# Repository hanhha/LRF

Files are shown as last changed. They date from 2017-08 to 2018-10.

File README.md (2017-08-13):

# LFR

A simple DIY laser range finder.

This is a very simple DIY laser range finder. For fast prototyping, I uses a Raspberry Pi 1 board with a web cam, a cheap laser diode (<5mW, I think) and some 3d printed bars to align the parts.

## Folder organization:

**src** - *all source code*

**eltr** - *all electric/electronic stuffs*

**model** - *all models of frame, mount, ... that would be 3d printed*

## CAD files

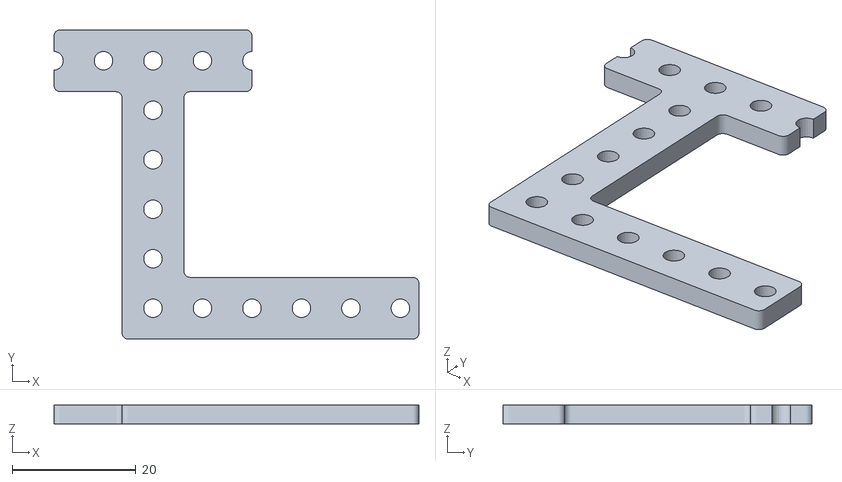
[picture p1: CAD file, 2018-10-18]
model/mount_L_shape.stl
59.0 x 50.0 x 3.00

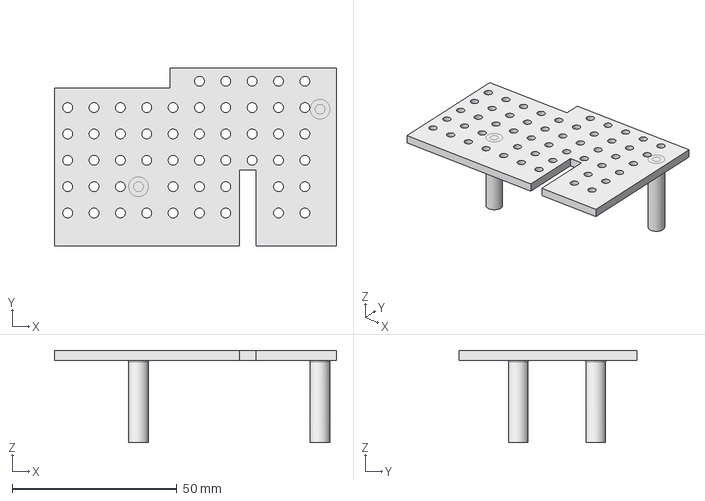
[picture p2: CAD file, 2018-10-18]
model/pi_top.FCStd
85.6 x 54.0 x 28.0 mm

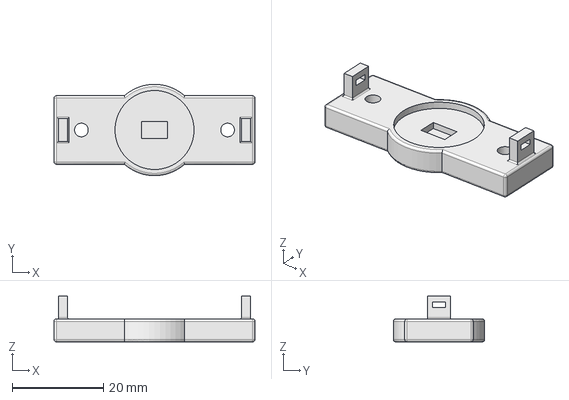
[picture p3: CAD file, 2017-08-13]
model/cam_mount.FCStd
44.0 x 20.0 x 10.0 mm

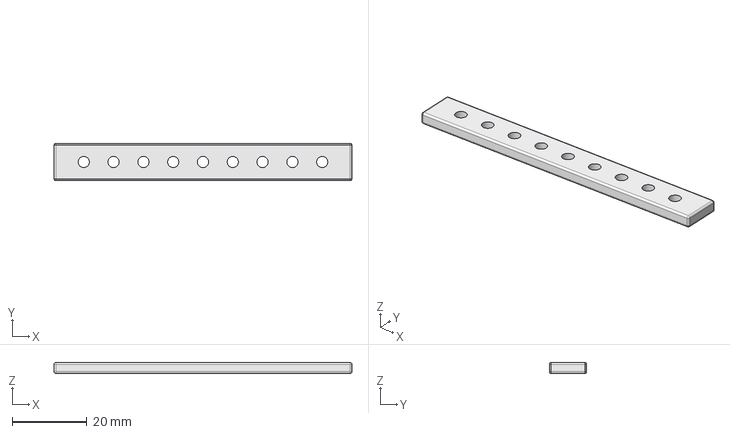
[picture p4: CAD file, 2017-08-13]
model/mount_bar.FCStd
80.0 x 10.0 x 3.00 mm

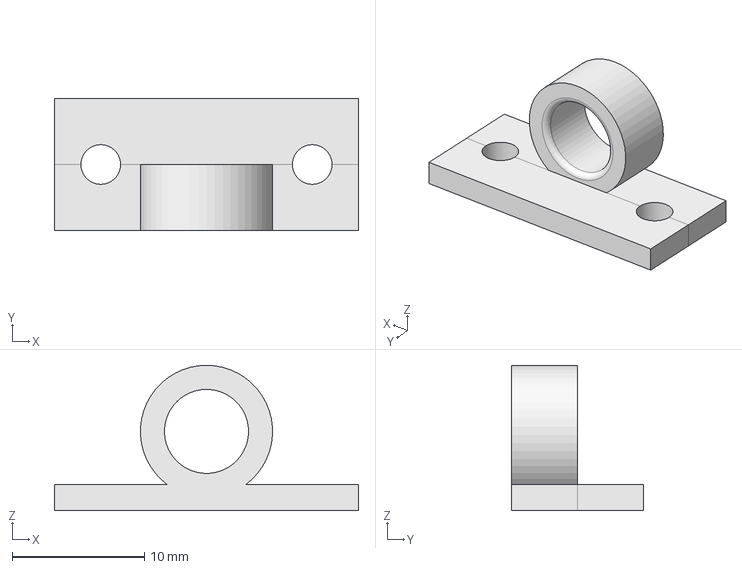
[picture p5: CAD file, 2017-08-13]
model/laser_diode_mount.FCStd
23.0 x 10.0 x 11.0 mm

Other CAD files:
model/mount_hLshape.FCStd
model/pi_top.stl

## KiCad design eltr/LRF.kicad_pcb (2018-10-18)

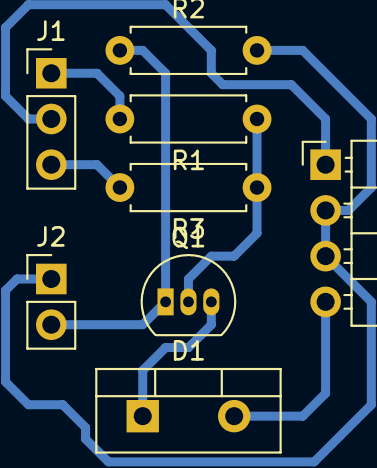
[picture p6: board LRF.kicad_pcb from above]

Board: 2 copper layers, 8 parts (0 on the bottom side), 8 nets.

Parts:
D1: Laser diode; TO-220-2_Vertical
J1: CONN_01X03_MALE; Pin_Header_Straight_1x03_Pitch2.54mm
J2: CONN_01X02_MALE; Pin_Header_Straight_1x02_Pitch2.54mm
P1: CONN_01X04; Pin_Header_Angled_1x04_Pitch2.54mm
Q1: PN2222A; TO-92_Inline_Narrow_Oval
R1: 100; R_Axial_DIN0207_L6.3mm_D2.5mm_P7.62mm_Horizontal
R2: 10K; R_Axial_DIN0207_L6.3mm_D2.5mm_P7.62mm_Horizontal
R3: 1K; R_Axial_DIN0207_L6.3mm_D2.5mm_P7.62mm_Horizontal

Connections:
+5V: D1.2, P1.4
GND: J2.1, P1.2, P1.3, R2.2
GPIO: J1.2, P1.1
unnamed: D1.1, Q1.3
unnamed: J1.1, R1.2
unnamed: J1.3, R3.2
unnamed: J2.2, Q1.1, R2.1
unnamed: Q1.2, R1.1, R3.1

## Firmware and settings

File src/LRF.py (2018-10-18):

#!/usr/bin/env python

import picamera as picam
from PIL import Image
from picamera.array import PiRGBArray
import numpy as np
import os
import RPi.GPIO as GPIO
import cv2

import curses

os.environ['SDL_VIDEODRIVER'] = 'fbcon'

imgDimensions = (800, 600)

camera = picam.PiCamera()
camera.resolution = imgDimensions 
camera.framerate = 40
camera.led = False
camera.iso = 30
camera.exposure_mode = 'snow'
rawCapture = PiRGBArray(camera, size=imgDimensions)

linear_params = {'A': 1, 'B': 0}

laserPin = 7

def laserSETUP ():
	GPIO.setup   (laserPin, GPIO.OUT)

def laserON ():
	GPIO.output (laserPin, GPIO.HIGH)

def laserOFF ():
	GPIO.output  (laserPin, GPIO.LOW)

def detectSpot (img):
	lab_img = cv2.cvtColor (img, cv2.COLOR_BGR2LAB)
	lw_range = np.array([240, 0,  0], dtype =np.uint8)
	up_range = np.array([255, 255, 255], dtype =np.uint8)
	mask = cv2.inRange (lab_img, lw_range, up_range)
	
	return mask

def getSpot (mask):
	spots = np.where (np.logical_and.reduce ((mask[0] == 255, mask[1] == 255)), 255, 0)
	return spots

def getSpotPos (spots):
	if spots[1].size == 0 or spots[0].size == 0:
		return None
	else:
		tmp = np.where (spots == 255)
		if tmp[1].size == 0 or tmp[0].size == 0:
			return None
		else:
			cx = np.sum (tmp[1]) / tmp[1].size 
			cy = np.sum (tmp[0]) / tmp[0].size 
			return (cx, cy)

def __main__ (stdscr):
	curses.init_pair (1, curses.COLOR_CYAN, curses.COLOR_BLACK)
	rate = 1
	stdscr.nodelay(1)

	GPIO.cleanup ()
	GPIO.setmode (GPIO.BOARD)
	laserSETUP   ()
	laserOFF     ()
	bg_mask      = None
	distance_txt = 'INF'
	mask         = []
	spots        = None
	laserSpot    = None
	phase        = 0

	for frame in camera.capture_continuous (rawCapture, format ="bgr", use_video_port=True):
		image = np.copy (frame.array) 

		if phase == 0:
			bg_mask = detectSpot(image)
			laserON ()
			mask = []
			phase = 1
		elif phase == 1:
			mask.append (detectSpot(image) - bg_mask)
			phase = 2
		elif phase == 2:
			mask.append (detectSpot(image) - bg_mask)
			phase = 3
		else:
			laserOFF ()
			phase = 0

			spots = getSpot (mask)
			laserSpot = getSpotPos (spots)
			if laserSpot is not None:
				p = laserSpot[0] - imgDimensions[0]/2
				if p != 0:
					distance = linear_params['A'] * float(p) + linear_params['B']
					distance_txt = str(distance) 
				else:
					distance_txt = 'INF'

		stdscr.move (1,1)
		stdscr.clrtoeol ()
		stdscr.addstr (1, 1, 'Distance: ' + distance_txt + 'cm', curses.color_pair(1))
		stdscr.refresh ()
		if stdscr.getch () == ord('q'):
			break
		
		rawCapture.truncate(0)
	
	camera.close()
	GPIO.cleanup ()

if __name__ == '__main__':
	curses.wrapper(__main__)
# EOF

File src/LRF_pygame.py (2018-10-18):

#!/usr/bin/env python

import picamera as picam
from PIL import Image
from picamera.array import PiRGBArray
import time
import pygame
from pygame.locals import *
import numpy as np
import os
import RPi.GPIO as GPIO
import cv2

os.environ['SDL_VIDEODRIVER'] = 'fbcon'

imgDimensions = (640, 480)
imgFrame = None
firstFrame = None
secondFrame = None
thirdFrame = None
forthFrame = None

camera = picam.PiCamera()
camera.resolution = imgDimensions 
camera.framerate = 40
camera.led = False
camera.iso = 30
camera.exposure_mode = 'snow'
rawCapture = PiRGBArray(camera, size=imgDimensions)

linear_params = {'A': 0.04395604396, 'B': 15.20879121}

screen = None

clock = pygame.time.Clock ()

laserPin = 7

def laserSETUP ():
	GPIO.setup   (laserPin, GPIO.OUT)

def laserON ():
	GPIO.output (laserPin, GPIO.HIGH)

def laserOFF ():
	GPIO.output  (laserPin, GPIO.LOW)

def initializePygame ():
	global screen, myfont
	global firstFrame, secondFrame, thirdFrame, forthFrame
	global imgFrame

	pygame.init()
	infoObj = pygame.display.Info ()
	imgFrame = (infoObj.current_w / 2, infoObj.current_h / 2)
	pygame.mouse.set_visible (False)
	screen = pygame.display.set_mode ((infoObj.current_w, infoObj.current_h), 0, 32)
	# Using default system font so that set it None
	myfont = pygame.font.SysFont (None, 30)
	firstFrame = (0,0)
	secondFrame = (infoObj.current_w / 2, 0)
	thirdFrame = (0,infoObj.current_h / 2)
	forthFrame = (infoObj.current_w / 2, infoObj.current_h / 2)

def stickImg (img, update = False, screen_frame = 0):
	if img is not None:
		pygameSurface = pygame.surfarray.make_surface (img.swapaxes(0,1))
		scaledSurface = pygame.transform.scale(pygameSurface, imgFrame) 
		if screen_frame == 0:
			screen.blit (scaledSurface, firstFrame)
		if screen_frame == 1:
			screen.blit (scaledSurface, secondFrame)
		if screen_frame == 2:
			screen.blit (scaledSurface, thirdFrame)
		if screen_frame == 3:
			screen.blit (scaledSurface, forthFrame)
	if update:
		pygame.display.update()

def stickSpot (spot, update = False):
	if spot is not None:
		sx = imgFrame[0] / float(imgDimensions[0])
		sy = imgFrame[1] / float(imgDimensions[1])
		scaled_spot = (int(spot[0] *sx), int(spot[1]*sy))
		pygame.draw.line (screen, (255,0,0), (scaled_spot[0], scaled_spot[1]-5), (scaled_spot[0], scaled_spot[1]+5), 2)
		pygame.draw.line (screen, (255,0,0), (scaled_spot[0]-5, scaled_spot[1]), (scaled_spot[0]+5, scaled_spot[1]), 2)
	if update:
		pygame.display.update()

def stickDistance (text, update = False):
	textSurface = myfont.render (text, True, (255,255,255))
	screen.blit (textSurface, tuple(map(sum,zip(forthFrame,(30,70)))))
	if update:
		pygame.display.update()

def stickFPS (text, update = False):
	textSurface = myfont.render (text, True, (255,255,255))
	screen.blit (textSurface, tuple(map(sum,zip(forthFrame,(30,10)))))
	if update:
		pygame.display.update()

def cleanScreen ():
	screen.fill ((0,0,0))

def detectSpot (img):
	lab_img = cv2.cvtColor (img, cv2.COLOR_BGR2LAB)
	lw_range = np.array([240, 0,  0], dtype =np.uint8)
	up_range = np.array([255, 255, 255], dtype =np.uint8)
	mask = cv2.inRange (lab_img, lw_range, up_range)
	
	return mask

def getSpot (mask):
	spots = np.where (np.logical_and.reduce ((mask[0] == 255, mask[1] == 255)), 255, 0)
	return spots

def getSpotPos (spots):
	if spots[1].size == 0 or spots[0].size == 0:
		return None
	else:
		tmp = np.where (spots == 255)
		cx = np.sum (tmp[1]) / tmp[1].size 
		cy = np.sum (tmp[0]) / tmp[0].size 
		return (cx, cy)

def __main__ ():
	GPIO.cleanup ()
	GPIO.setmode (GPIO.BOARD)
	laserSETUP ()
	initializePygame ()
	laserOFF ()
	bg_mask = None
	distance_txt = 'INF'
	mask = []
	spots = None
	laserSpot = None
	phase = 0

	for frame in camera.capture_continuous (rawCapture, format ="bgr", use_video_port=True):
		image = np.copy (frame.array) 
		cleanScreen ()

		if phase == 0:
			bg_mask = detectSpot(image)
			laserON ()
			mask = []
			phase = 1
		elif phase == 1:
			mask.append (detectSpot(image) - bg_mask)
			stickImg (mask[-1], screen_frame = 1)
			phase = 2
		elif phase == 2:
			mask.append (detectSpot(image) - bg_mask)
			stickImg (mask[-1], screen_frame = 1)
			phase = 3
		else:
			laserOFF ()
			phase = 0

			spots = getSpot (mask)
			laserSpot = getSpotPos (spots)
			if laserSpot is not None:
				p = laserSpot[0] - imgDimensions[0]/2
				if p != 0:
					distance = linear_params['A'] * float(p) + linear_params['B']
					distance_txt = str(distance) 
				else:
					distance_txt = 'INF'

		stickImg (image)
		stickSpot (laserSpot)
		stickFPS ('FPS ' + str(clock.get_fps()))
		stickImg (bg_mask, screen_frame = 2)
		stickDistance ('Distance: ' + distance_txt + 'cm', update = True)
		
		clock.tick ()
		for event in pygame.event.get ():
			if event.type == QUIT:
				pygame.quit ()
				GPIO.cleanup ()
				sys.exit ()
			if event.type == KEYDOWN and event.key == K_q:
				pygame.quit ()
				GPIO.cleanup ()
				return

		rawCapture.truncate(0)
	
	camera.close()
	pygame.quit ()
	GPIO.cleanup ()

# call main
__main__()
# EOF

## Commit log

2017-08-13 Added the circuit to control laser diode using RPI GPIO pin
    [LRF.kicad_pcb, LRF.sch]
2017-08-13 Add model for mounting camera, laser diode
    [cam_mount.FCStd, laser_diode_mount.FCStd, mount_bar.FCStd]
2017-12-12 Adding source to test camera module
2017-12-13 Control laser
2017-12-18 Detect laser point
2018-10-18 Cleaning up
    [LRF.kicad_pcb, LRF.sch, mount_L_shape.stl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]
